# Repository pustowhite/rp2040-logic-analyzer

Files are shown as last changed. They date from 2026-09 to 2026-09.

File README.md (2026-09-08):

# RP2040 Logic Analyzer

An eight-channel logic analyzer hardware project built around the Raspberry Pi RP2040, with a custom two-layer PCB, USB-C connectivity, and selectable 1.8 V / 3.3 V input logic modes.

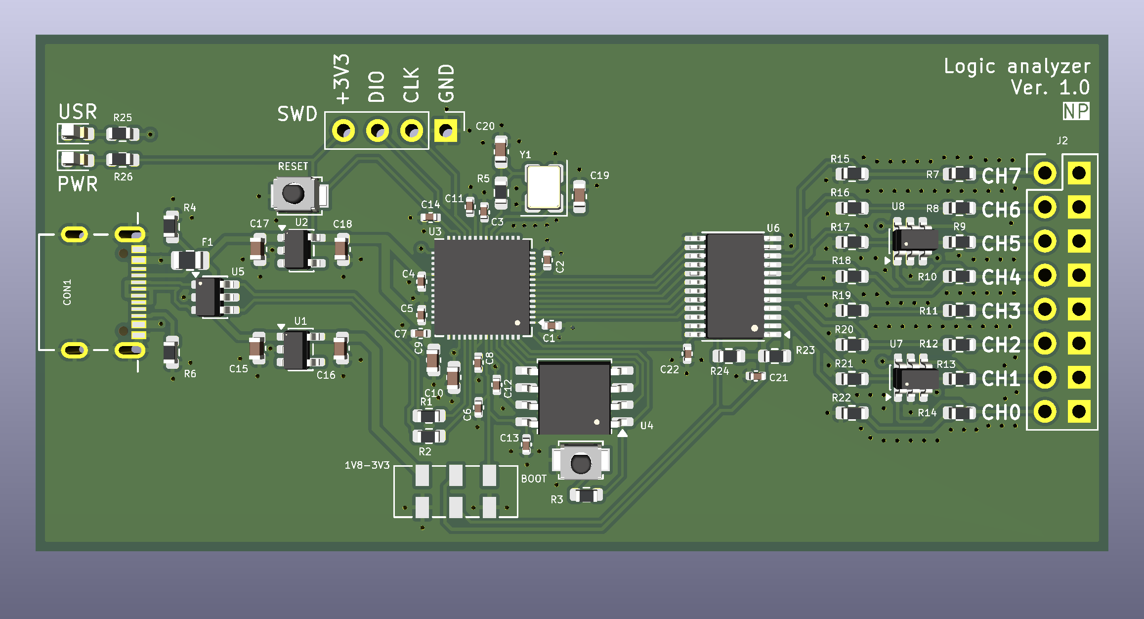
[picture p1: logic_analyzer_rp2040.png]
RP2040 Logic Analyzer


I developed this project to gain practical experience in circuit design and PCB layout, from the input interface and power supplies to the microcontroller support circuitry. It is part of my electronics engineering portfolio.

## Hardware overview

| Item | Design |
| --- | --- |
| Microcontroller | Raspberry Pi RP2040 |
| Digital inputs | 8 channels |
| Intended input logic modes | 1.8 V and 3.3 V, selected by a physical switch |
| Input level translator | SN74LVC8T245 |
| Input protection components | Two SRV05-4 arrays |
| Input connector | 2 x 8, 2.54 mm header, with alternating signal and ground pins |
| USB connector | TYPEC-304-ACP16 |
| USB protection component | USBLC6-2SC6 |
| External program memory | W25Q32JVSS |
| Power | USB 5 V input; TLV75533PDBV and TLV75518PDBV regulators |
| Debug interface | Four-pin SWD header |
| PCB | Two copper layers; 79.7 x 50.7 mm outline in the included layout |
| CAD | KiCad 10.0, as recorded in the source files |

The voltage modes describe the intended logic families. Input thresholds, maximum reliable signal frequency, and protection performance still require verification on the assembled board.

## How it work

Eight external digital signals enter through the input header. The input network and SN74LVC8T245 interface these signals to the RP2040's 3.3 V domain. USB-C supplies power and provides the physical connection to the host computer.

The planned capture implementation uses the RP2040's programmable I/O (PIO) to sample the inputs and direct memory access (DMA) to move samples into RAM. Capture firmware and host software are not included in this snapshot. Sampling rate, capture depth, trigger functions, and protocol decoding are therefore not presented as implemented features.

## Engineering work

The project brings together several parts of a complete PCB design:

- An eight-channel input interface with selectable translator supply voltage.
- RP2040 support circuitry, external flash, a crystal, and local decoupling.
- USB-C power and data connections with protection components.
- Component placement, signal routing, and ground copper on a two-layer board.
- Integration of a custom connector symbol and footprint into a portable KiCad project.

Component documentation describes the individual devices; it does not establish the measured performance of this board.

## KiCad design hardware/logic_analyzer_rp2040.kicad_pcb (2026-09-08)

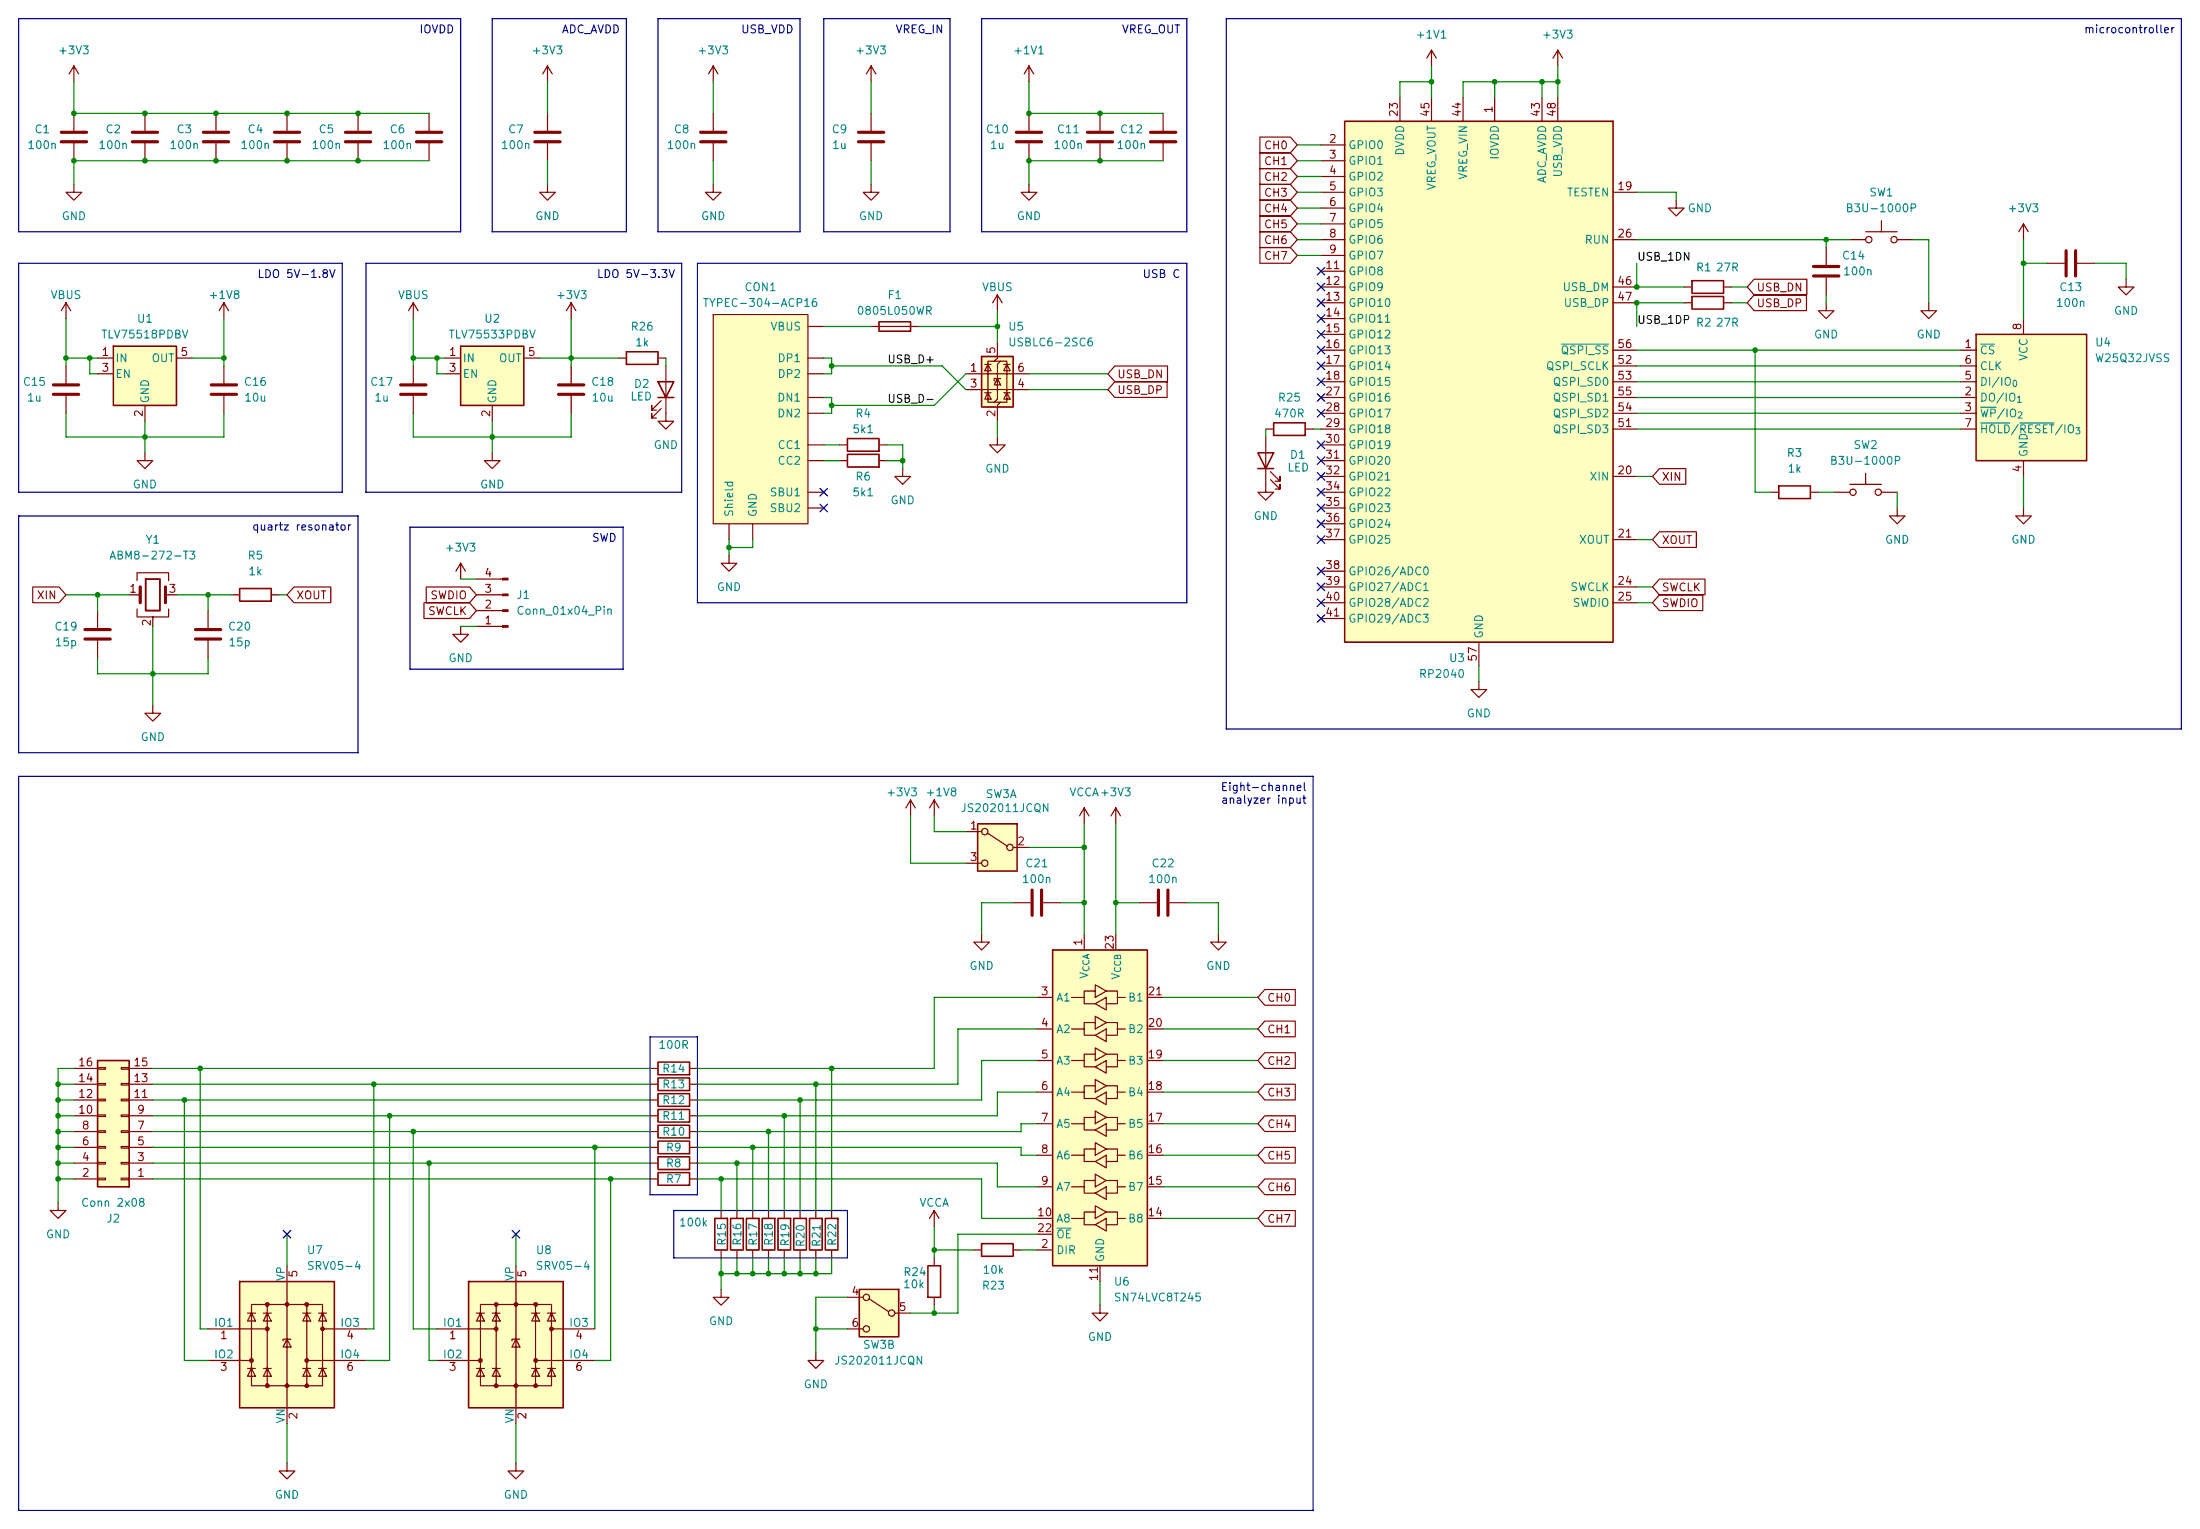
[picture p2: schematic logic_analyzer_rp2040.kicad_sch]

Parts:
C1, C2, C3, C4, C5, C6, C7, C8, C11, C12, C13, C14, C21, C22: 100n; C_0402_1005Metric
C9, C10, C15, C17: 1u; C_0603_1608Metric
C16, C18: 10u; C_0603_1608Metric
C19, C20: 15p; C_0603_1608Metric
CON1: TYPEC-304-ACP16; LCSC C2982555
D1, D2: LED; LED_0603_1608Metric
F1: 0805L050WR; Fuse_0805_2012Metric
J1: Conn_01x04_Pin; PinHeader_1x04_P2.54mm_Vertical
J2: Conn 2x08; PinHeader_2x08_P2.54mm_Vertical
R1, R2: 27R; R_0603_1608Metric
R3, R5, R26: 1k; R_0603_1608Metric
R4, R6: 5k1; R_0603_1608Metric
R7, R8, R9, R10, R11, R12, R13, R14: 100R; R_0603_1608Metric
R15, R16, R17, R18, R19, R20, R21, R22: 100k; R_0603_1608Metric
R23, R24: 10k; R_0603_1608Metric
R25: 470R; R_0603_1608Metric
SW1, SW2: B3U-1000P; SW_SPST_B3U-1000P
SW3: JS202011JCQN; SW_DPDT_CK_JS202011JCQN
U1: TLV75518PDBV; SOT-23-5
U2: TLV75533PDBV; SOT-23-5
U3: RP2040; QFN-56-1EP_7x7mm_P0.4mm_EP3.2x3.2mm
U4: W25Q32JVSS; SOIC-8_5.3x5.3mm_P1.27mm
U5: USBLC6-2SC6; SOT-23-6
U6: SN74LVC8T245; TSSOP-24_4.4x7.8mm_P0.65mm
U7, U8: SRV05-4; SOT-23-6
Y1: ABM8-272-T3; Crystal_SMD_3225-4Pin_3.2x2.5mm

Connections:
+1V1: C10.2, C11.2, C12.2, U3.23 (DVDD), U3.45 (VREG_VOUT), U3.50 (DVDD)
+1V8: C16.2, SW3.1 (A), U1.5 (OUT); also elsewhere on the board
+3V3: C1.2, C2.2, C3.2, C4.2, C5.2, C6.2, C7.2, C8.2, C9.2, C13.2, C18.2, C22.1, J1.4, R26.2, SW3.3 (C), U2.5 (OUT), U3.1 (IOVDD), U3.10 (IOVDD), U3.22 (IOVDD), U3.33 (IOVDD), U3.42 (IOVDD), U3.43 (ADC_AVDD), U3.44 (VREG_VIN), U3.48 (USB_VDD), U3.49 (IOVDD), U4.8 (VCC), U6.23 (V_{CCB}), U6.24 (V_{CCB}); also elsewhere on the board
/USB_1DN: R1.2, U3.46 (USB_DM)
/USB_1DP: R2.2, U3.47 (USB_DP)
/USB_D+: CON1.A6 (DP1), CON1.B6 (DP2), U5.3 (I/O2)
/USB_D-: CON1.A7 (DN1), CON1.B7 (DN2), U5.1 (I/O1)
CH0: U3.2 (GPIO0), U6.21 (B1)
CH1: U3.3 (GPIO1), U6.20 (B2)
CH2: U3.4 (GPIO2), U6.19 (B3)
CH3: U3.5 (GPIO3), U6.18 (B4)
CH4: U3.6 (GPIO4), U6.17 (B5)
CH5: U3.7 (GPIO5), U6.16 (B6)
CH6: U3.8 (GPIO6), U6.15 (B7)
CH7: U3.9 (GPIO7), U6.14 (B8)
GND: C1.1, C2.1, C3.1, C4.1, C5.1, C6.1, C7.1, C8.1, C9.1, C10.1, C11.1, C12.1, C13.1, C14.1, C15.1, C16.1, C17.1, C18.1, C19.2, C20.1, C21.1, C22.2, CON1.GND1 (GND), CON1.GND2 (GND), CON1.S1 (Shield), CON1.S2 (Shield), CON1.S3 (Shield), CON1.S4 (Shield), D1.1 (K), D2.1 (K), J1.1, J2.2, J2.4, J2.6, J2.8, J2.10, J2.12, J2.14, J2.16, R4.2, R6.2, R15.1, R16.1, R17.1, R18.1, R19.1, R20.1, R21.1, R22.1, SW1.1, SW2.1, SW3.4 (A), SW3.6 (C), U1.2 (GND), U2.2 (GND), U3.19 (TESTEN), U3.57 (GND), U4.4 (GND), U5.2 (GND), U6.11 (GND), U6.12 (GND), U6.13 (GND), U7.2 (VN), U8.2 (VN), Y1.2 (G), Y1.4 (G); also elsewhere on the board
unnamed: C20.2, R5.1, Y1.3
unnamed: CON1.A5 (CC1), R4.1
unnamed: CON1.B5 (CC2), R6.1
unnamed: CON1.VBUS1 (VBUS), CON1.VBUS2 (VBUS), F1.1
unnamed 20: D1.2 (A), R25.1; also elsewhere on the board
unnamed 21: D2.2 (A), R26.1; also elsewhere on the board
unnamed: J2.1, R7.1, U8.6 (IO4)
unnamed: J2.3, R8.1, U8.3 (IO2)
unnamed: J2.5, R9.1, U8.4 (IO3)
unnamed: J2.7, R10.1, U8.1 (IO1)
unnamed: J2.9, R11.1, U7.6 (IO4)
unnamed: J2.11, R12.1, U7.3 (IO2)
unnamed: J2.13, R13.1, U7.4 (IO3)
unnamed: J2.15, R14.1, U7.1 (IO1)
unnamed 30: R3.1, SW2.2; also elsewhere on the board
unnamed 31: R24.2, SW3.5 (B), U6.22 (~OE); also elsewhere on the board
unnamed: R25.2, U3.29 (GPIO18)
unnamed: U3.52 (QSPI_SCLK), U4.6 (CLK)
unnamed: U3.53 (QSPI_SD0), U4.5 (DI/IO_{0})
unnamed: U3.55 (QSPI_SD1), U4.2 (DO/IO_{1})
unnamed: U3.54 (QSPI_SD2), U4.3 (~WP/IO_{2})
unnamed: U3.51 (QSPI_SD3), U4.7 (~HOLD/~RESET/IO_{3})
unnamed 38: C14.2, SW1.2, U3.26 (RUN); also elsewhere on the board
unnamed: R3.2, U3.56 (~QSPI_SS), U4.1 (~CS)
unnamed: R14.2, R22.2, U6.3 (A1)
unnamed: R13.2, R21.2, U6.4 (A2)
unnamed: R12.2, R20.2, U6.5 (A3)
unnamed: R11.2, R19.2, U6.6 (A4)
unnamed: R10.2, R18.2, U6.7 (A5)
unnamed: R9.2, R17.2, U6.8 (A6)
unnamed: R8.2, R16.2, U6.9 (A7)
unnamed: R7.2, R15.2, U6.10 (A8)
unnamed: R23.1, U6.2 (DIR)
SWCLK: J1.2, U3.24 (SWCLK); also elsewhere on the board
SWDIO: J1.3, U3.25 (SWDIO); also elsewhere on the board
USB_DN: R1.1, U5.6 (I/O1)
USB_DP: R2.1, U5.4 (I/O2)
VBUS: C15.2, C17.2, F1.2, U1.1 (IN), U1.3 (EN), U2.1 (IN), U2.3 (EN), U5.5 (VBUS)
VCCA: C21.2, R23.2, R24.1, SW3.2 (B), U6.1 (V_{CCA}); also elsewhere on the board
XIN: C19.1, U3.20 (XIN), Y1.1
XOUT: R5.2, U3.21 (XOUT)

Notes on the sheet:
LDO 5V-3.3V
USB C
SWD
IOVDD
ADC_AVDD
VREG_IN
VREG_OUT
LDO 5V-1.8V
quartz resonator
microcontroller
USB_VDD
Eight-channel analyzer input

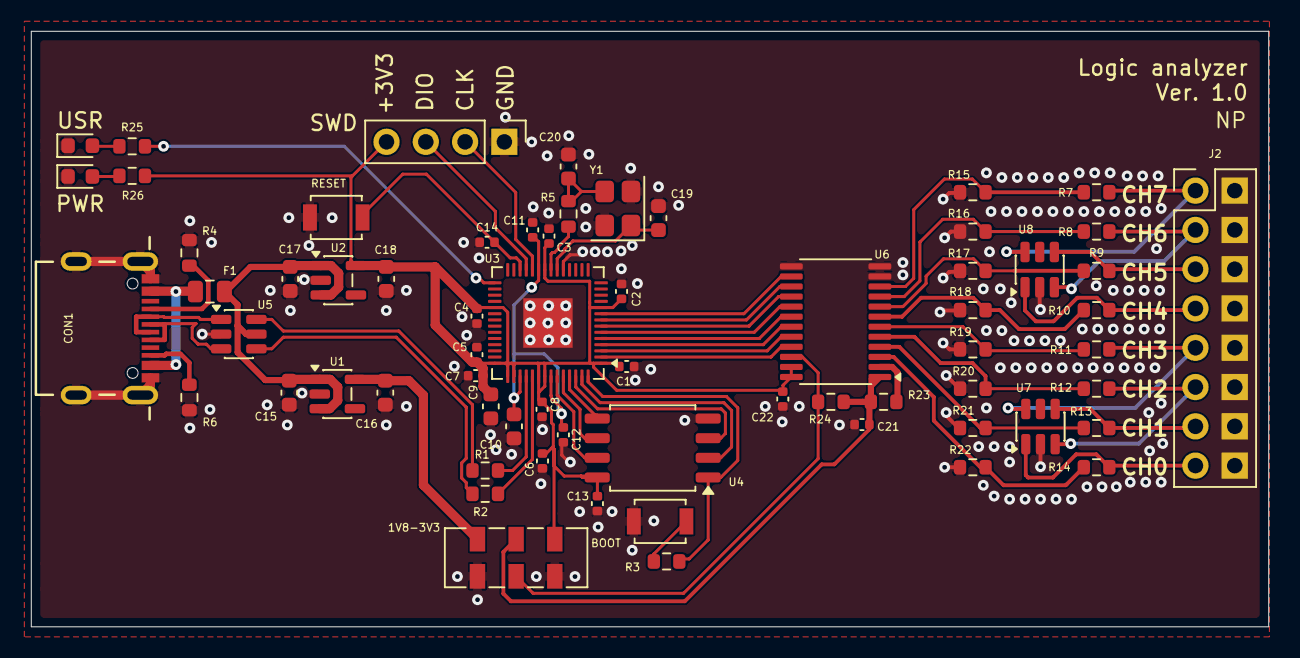
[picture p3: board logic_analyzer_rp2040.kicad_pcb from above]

Board: 2 copper layers, 80.0 x 38.5 mm, 66 parts (0 on the bottom side), 57 nets.

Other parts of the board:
1V8-3V3: JS202011JCQN; SW_DPDT_CK_JS202011JCQN
BOOT: B3U-1000P; SW_SPST_B3U-1000P
PWR: LED; LED_0603_1608Metric
RESET: B3U-1000P; SW_SPST_B3U-1000P
SWD: Conn_01x04_Pin; PinHeader_1x04_P2.54mm_Vertical
USR: LED; LED_0603_1608Metric

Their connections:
+1V8: 1V8-3V3.1 (A); also elsewhere on the board
+3V3: 1V8-3V3.3 (C), SWD.4; also elsewhere on the board
GND: 1V8-3V3.4 (A), 1V8-3V3.6 (C), BOOT.1, PWR.1 (K), RESET.1, SWD.1, USR.1 (K); also elsewhere on the board
unnamed 20: USR.2 (A); also elsewhere on the board
unnamed 21: PWR.2 (A); also elsewhere on the board
unnamed 30: BOOT.2; also elsewhere on the board
unnamed 31: 1V8-3V3.5 (B); also elsewhere on the board
unnamed 38: RESET.2; also elsewhere on the board
SWCLK: SWD.2; also elsewhere on the board
SWDIO: SWD.3; also elsewhere on the board
VCCA: 1V8-3V3.2 (B); also elsewhere on the board
